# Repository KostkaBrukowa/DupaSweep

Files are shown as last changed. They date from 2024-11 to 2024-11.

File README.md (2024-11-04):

# DupaSweep
## An autogenerated split 36 key [Sweep](https://github.com/davidphilipbarr/Sweep) clone based on [ samoklava ](https://github.com/soundmonster/samoklava)

left | right
-|-
left | right

Without keycaps:
without keycaps

This keyboard was generated using [Ergogen](https://github.com/ergogen/ergogen).
If you want to make some changes look in above repository for details.

A 5x3 split keyboard with 3 thumb keys. There is nothing unique about the keyboard layout. It's practically choc mini Sweep keyboard with
extra key and no TRRS. I've removed TRRS to support diode-less build for wireless option.

Top outlines matches Exactly the original sweep outlines, bottom outlines are adjusted to the extra key.

I also provide [ZMK config](zmk-config) for this keyboard with my own keymap.

Gerber files are available in [this directory](./gerbers). I've successfully managed to order it on
[JLPCB](https://jlcpcb.com/) website, and it works well.

See the [workflow](.github/workflows/build.yml) or the [Makefile](ergogen/Makefile) for more details.

## Run locally:

`docker images`
`❯ docker run -v $(pwd)/output:/output c8ab98c1df67 python /usr/lib/python2.7/dist-packages/kicad-automation/pcbnew_automation/export_dsn.py /output/pcbs/board.kicad_pcb /output/pcbs/board.dsn`
`❯ docker run -v $(pwd)/output:/output f4c89f58fd11 java -jar /opt/freerouting_cli.jar -de /output/pcbs/board.dsn -do /output/pcbs/board.ses`
`❯ docker run -v $(pwd)/output:/output c8ab98c1df67 /usr/lib/python2.7/dist-packages/kicad-automation/pcbnew_automation/import_ses.py /output/pcbs/board.kicad_pcb /output/pcbs/board.ses`
`❯ docker run -v $(pwd)/output:/output sha256:8a361e9808f9ae25d86478e5110e61046024c97a23c6e60b45989cfe6ce3e040 kikit fab jlcpcb --no-assembly /output/pcbs/board.kicad_pcb /output/gerbers/board`

case:
`npx @jscad/cli@1 output/cases/bottom.jscad -of stla -o bottom.stl `

To add wall to the case:
https://www.youtube.com/watch?v=7UXsD7nSfDY
https://forums.autodesk.com/t5/fusion-design-validate-document/is-there-a-way-to-merge-faces/td-p/6891321
Then extrude in solid body

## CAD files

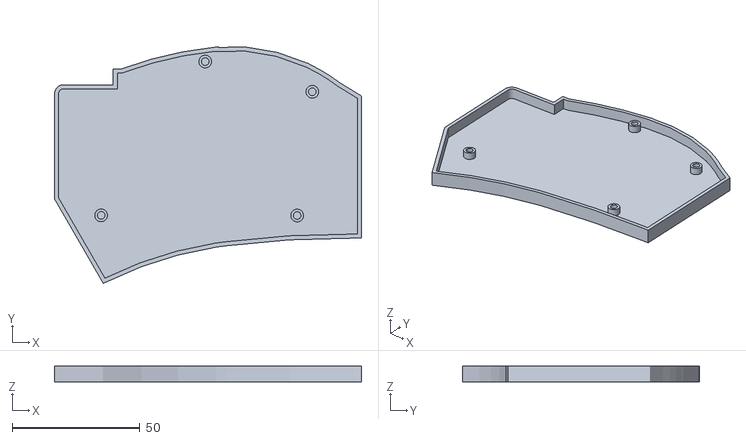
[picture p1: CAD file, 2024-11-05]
ergogen/case v1 - right.stl
120.2 x 92.7 x 6.10

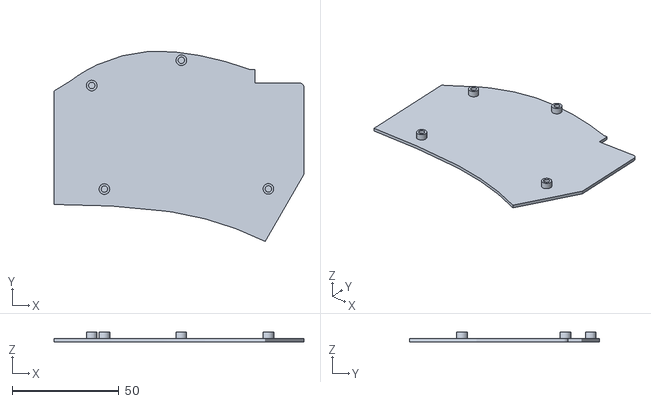
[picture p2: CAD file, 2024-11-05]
ergogen/case.stl
117.0 x 88.9 x 4.50

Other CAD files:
ergogen/case v1.stl

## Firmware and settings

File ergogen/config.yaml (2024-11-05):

units:
  kx: cx
  ky: cy
  px: 2
  py: 2
  ring_rotate: -10
    # Defaults to M2 Screws
  screwSize: 1.5
  pcbHoleSize: 2
  standoffSize: 2.5
points:
  zones:
    matrix:
      columns:
        pinky:
          key:
            origin: [ 0, -1cy ]
          rows:
            bottom:
              column_net: P21
            home:
              column_net: P20
            top:
              column_net: P19
        ring:
          key:
            rotate: 0
            stagger: 12.23
            spread: cx
          rows:
            bottom:
              column_net: P18
            home:
              column_net: P15
            top:
              column_net: P14
        middle:
          key:
            origin: [ 0, -1cy ]
            rotate: 0
            stagger: 4.46
            spread: cx
          rows:
            bottom:
              column_net: P16
            home:
              column_net: P10
            top:
              column_net: P9
        index:
          key:
            origin: [ 0, -1cy ]
            rotate: 0
            stagger: -4.86
            spread: cx
          rows:
            bottom:
              column_net: P8
            home:
              column_net: P7
            top:
              column_net: P6
        inner:
          key:
            origin: [ 0, -1cy ]
            rotate: 0
            spread: cx
            stagger: -1.88
          rows:
            bottom:
              column_net: P5
            home:
              column_net: P4
            top:
              column_net: P3
      rows:
        bottom:
          padding: 1ky
        home:
          padding: 1ky
        top:
          padding: 1ky
    thumbfan:
      anchor:
        ref: matrix_inner_bottom
        shift: [ 7.5, -25.06 ]
      columns:
        right:
          key:
            origin: [-cx/2, -cy/2]
            stagger: 5.64
            spread: -3.04
            splay: -30
            column_net: P2
            column_mark: R
        middle:
          key:
            origin: [-cx/2, -cy/2]
            splay: 15
            stagger: -4.72
            spread: -cx + 0.27
            column_net: P0
            column_mark: M
        left:
          key:
            origin: [-cx/2, -cy/2]
            stagger: -4.4
            spread: -cx + 0.6
            splay: 14
            column_net: P1
            column_mark: P
      rows:
        thumb:
          padding: 0
outlines:
  # board dimensions according to JLCPCB: 122.28 mm x 101.05 mm
    raw:
      - what: rectangle
        size: [kx, ky]
        corner: px
        where: true
    top_arc_left_intersect:
      - what: polygon
        points:
          - ref: matrix_pinky_top
            shift: [-cx/2, cy/2]
          - ref: matrix_middle_top
            shift: [cx/2, cy/2]
          - ref: matrix_middle_top
            shift: [cx/2, 2cy]
          - ref: matrix_pinky_top
            shift: [-cx/2, 3cy]
    top_arc_right_intersect:
      - what: polygon
        points:
          - ref: matrix_middle_top
            shift: [cx/2, -cy/2]
          - ref: matrix_middle_top
            shift: [cx/2, 2cy]
          - ref: matrix_inner_top
            shift: [cx/2, 3cy]
          - ref: matrix_inner_top
            shift: [cx/2, cy/2]
    bottom_arc_left_intersect:
      - what: polygon
        points:
          - ref: matrix_pinky_bottom
            shift: [-cx/2 - 2, cy/2]
          - ref: matrix_middle_bottom
            shift: [cx/2, cy/2]
          - ref: matrix_middle_bottom
            shift: [cx/2, -4cy]
          - ref: matrix_pinky_bottom
            shift: [-cx/2, -3cy]
    bottom_arc_right_intersect:
      - what: polygon
        points:
          - ref: matrix_middle_bottom
            shift: [cx/2, -cy/2]
          - ref: thumbfan_right_thumb
            shift: [cx/2, cy/2]
          - ref: thumbfan_right_thumb
            shift: [cx, -cy/2]
          - ref: thumbfan_right_thumb
            shift: [-2.1cx, -4cy]
    right_cut:
      - what: polygon
        points:
          - ref: thumbfan_right_thumb
            shift: [cx/2 + 2, -cy/2]
          - ref: thumbfan_right_thumb
            shift: [cx/2 + 2, 5cy]
          - ref: thumbfan_right_thumb
            shift: [3cx, 5cy]
          - ref: thumbfan_right_thumb
            shift: [3cx, -cy/2]

    arc_top_left: #todo check with top left corner shift
      - what: circle
        adjust:
          ref: matrix_middle_bottom
          shift: [2.2, -24.22]
        radius: 68.7
      - what: outline
        name: top_arc_left_intersect
        operation: intersect
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

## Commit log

2024-10-30 removes top and bottom plate
2024-11-02 Adds case with mounting hole but without wall
2024-11-04 Switched to choc
    [case.stl]
2024-11-04 Adds case
    [case v1.stl, case.stl]
2024-11-05 Adds more space for pad
    [case v1 - right.stl, case v1.stl, case.stl]
